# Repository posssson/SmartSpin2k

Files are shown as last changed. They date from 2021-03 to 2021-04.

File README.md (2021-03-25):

Watch the video (https://youtu.be/cPiIlZ2P5Ac)
Http://GitHub.com/doudar/SmartSpin2K
# SmartSpin2K

Hardware (3d Printed) and Software Project that uses an ESP32 and stepper motor to control spin bikes that have a resistance knob. 
The initial target was to use it with Zwift: stationary bike up hills and feel the burn. 

Optionally, the SmartSpin2K project has also progressed to the point of where it's useful without the hardware as a BLE device multiplexer, heart rate to watt converter (estimator), and proprietary BLE device to normal FTMS protocol converter using only the redily availiable ~$6 ESP32 devkit.   

## Background
I travel for a living and some hotels I stay at have spin bikes. I started carrying my own power meter pedals for the spin bikes so I could ride Zwift, but the experience just isn't the same without automatic resistance on the hills. Then one day I was looking down at that simple to turn knob and I had a thought - With the power meter pedals attached, almost everything is already in place on this $300 spin bike to turn it into the equivalent of a $3,000 computer controlled smart bike! And so here we are....

## NEW Instrucable!
Check it out at https://www.instructables.com/Spin-Bike-Controller/

## Summary of function

Communications Overview 

Your power meter (Or optionally the SmartSpin2K's built in HR->PWR calculation) connects to SmartSpin2k which then relays power and cadence to Zwift (or any other cycling app) via bluetooth as a controllable smart trainer. SmartSpin2k simulates gradient recieved from the app by automatically turning the knob a set amount for each percent grade change on your virtual road. SmartSpin2k also supports ERG mode which lets the unit directly control your resistance to match a specified watt target set by the connected app. In addition to adjusting the knob, SmartSpin2k also has shifter buttons to simulate virtual shifting. One of the nice features of having these shifters is that you can use them in ERG mode to get a jump on upcoming intervals. 

There are a multitude of configuration options availiable via a web interface on the SmartSpin2k. Automatic updates are also preformed on a regular basis if you choose to connect SmartSpin2k to your home network.  

### Recomended Hardware:

You'll need the quantity listed below of each item except the driver board. An optional PCB is in the hardware library which makes the wiring much simpler! 

| qty | Part | Amazon | Aliexpress |
|-----|:---:|---|---|
| 1 | ESP32 Dev Board | https://amzn.to/2ZNyjQX | https://www.aliexpress.com/item/1005001267643044.html |
| 1 | NEMA 17 Pancake Stepper | https://amzn.to/37mKKHh | https://www.aliexpress.com/item/4000120288783.html |
| 1 | TMC2225 | https://amzn.to/3kctdEQ | https://www.aliexpress.com/item/4000296898203.html |
| 1 | LM2596 Buck Converter | https://amzn.to/33ofggY | https://www.aliexpress.com/item/33014890815.html |
| 1 | 24V Power Supply | https://amzn.to/3r4e1i0 | https://www.aliexpress.com/item/32975192317.html |
| 2 | Tactile Switches | https://amzn.to/33ezmKx | https://www.aliexpress.com/item/32958087576.html |
| 2 | 608 Skate Bearings | https://amzn.to/3isBzrW | https://www.aliexpress.com/item/32700232097.html | 

So for $700-$1000 (or much less if you use HR2VP) you can build a fully functional smart bike! If you already have a Peloton bike collecting dust in the corner, this will work on that too! 

Surprisingly, my spin bike with the SmartSpin2K actually has better "road feel" than my expensive bike trainer, and since it's a belt drive bike, it's virtually silent. That's somthing you cannot achieve with a chain driven bike on any smart trainer. 

# NEW! - Small quantity of kits availiable!
If you would like a kit with a PCB, send a request to SmartSpin2K@gmail.com . Cost is $175 + shipping for all the printed parts + electronics, for an "almost ready to use unit". Note that if you go this route, this is still an open source hardware project and responsibility lies with **you** as to the proper construction and use. As such, you'll want to at least pull the cover off before use and take a look to ensure it's built to your standards (I think it's pretty good:) I'll be putting these togather on an as ordered basis, so expect 3-5 days prior to shipping.  Please see https://github.com/doudar/SmartSpin2k/wiki/Fitting-the-SmartSpin2k!

### We're working really hard on full documentaion
If you're adventerious and handy you can probably take a look at my pictures below or the assembly video and start tinkering. Please check out our new Instructable at https://www.instructables.com/Spin-Bike-Controller/ If there are any questions on the Instructable, please add info in the discussions and we will clarify there and on the new Instructable. This is a growing community and we now have a few members that would love to help you to get your SmartSpin2k working. There's also a wiki at https://github.com/doudar/SmartSpin2k/wiki 

In short, the process is:

### If you aren't a software developer:
1. Download https://github.com/doudar/SmartSpin2k/releases/download/0.1.1.11/firmware.bin
2. Download the SmartSpin2K flash tool https://github.com/SmartSpin2K/SmartSpin2kFlasher/releases/
3. Plug in your ESP32, open the SmartSpin2K flash tool and flash the firmware.bin.
4. Connect to the new wireless network SmartSpin2K (password is password) and enter your home network information, then the ESP32 will finish the installation automatically. 

### If you are a developer: 
1. Install Microsoft Visual Code. https://code.visualstudio.com/
2. Install PlatformIO into Visual Code. https://platformio.org/platformio-ide
3. Open this project in PlatformIO.  
4. Compile the project and upload to an ESP32

### Continue from either method above:
5. Print all the hardware. You'll need 1 Bottom Case, 1 Knob Cup, Both Spur Gears, 1 Stepper Crossbar, 1 Top Cover and a knob insert that fits your spin bike. PETG works well for printing all hardware.
6. If you're using the same switches for the shifters, you can optionally print the provided files. Previously I was using tape as a protective enclosure and it worked fine (if ugly).
7. Wire all of the connections outside the case. Use push on connectors if possible. 
8. Press both bearings into the recess.
9. Install the power supply, stepper driver and ESP32 into their brackets.
10. Install the power plug and shifter plug. 
11. Push the large gear down into the bearing. From the other side slide the knob cup onto it's shaft.  
12. Attach the stepper crossbar to the stepper motor.
13. Install the stepper motor. 
14. Put the cover on. 
15. Connect to the SmartSpin2k Wifi network for initial configuration. Default password is "password". If connecting via mobile, the configuration page should automatically pop up. 
16. Once configured on your local network, you can easily find the Smartspin2k by going to http://SmartSpin2K.local/

For some additional help, there are assembly pictures here that will be going into an instructable. https://github.com/doudar/SmartSpin2k/tree/master/Pictures/Assembly

ummm that was easy...right? :)

### Esp32 Connection Diagram
esp32 connections 

### TMC2225 Connection Diagram
esp32 connections 

*note, you can use an A4988 stepper driver also but you'll need to manually set the driver current with a screwdriver as well as possibly modify the output pin settings in /include/settings.h . If you do so, you'll aslo want to turn off automatic firmware updates. 

Cad Preview

The Finished assembly looks somthing like this prototype. 

On bench with shifters

Here it is mounted on a bike (ignore the piece of wood, it's no longer needed with a different hard attachment strap). 



Installed on a random Schwinn bike at the Gym:
Installed On Schwinn

...And here it is on a cheap magnetic HMC trainer off Amazon:
Installed on HMC

Here is the earliest prototype mounted on a spin bike. (Cardboard wrapped in ducktape enclosure :) ) 

Assembled SideView

Any help or feedback is greatly appreciated.

## Contributing
1. Install Microsoft Visual Code. https://code.visualstudio.com/
2. Install PlatformIO into Visual Code. https://platformio.org/platformio-ide
3. Install Pre-commit. https://pre-commit.com
4. Install pre-push git hooks: `pre-commit install --hook-type pre-push`
5. Open this project in PlatformIO.

## Licensing
The hardware designs in this project are licensed under the [CERN Open Hardware Licence Version 2 - Permissive license](Hardware/LICENSE).
The software in this project is licensed under the [GNU GENERAL PUBLIC LICENSE Version 2, June 1991 license](LICENSE).

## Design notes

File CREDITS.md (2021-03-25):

# Credits
Thanks to the authors of these libraries :
- [NimBLE-Arduino](https://github.com/h2zero/NimBLE-Arduino)
- [ArduinoJson](https://arduinojson.org)
- [TMCStepper](https://github.com/teemuatlut/TMCStepper)
- [Universal-Arduino-Telegram-Bot](https://github.com/witnessmenow/Universal-Arduino-Telegram-Bot)
- [FastAccelStepper](https://github.com/gin66/FastAccelStepper)

Thanks to Neil Kolban for his [BLE code examples](https://github.com/nkolban).

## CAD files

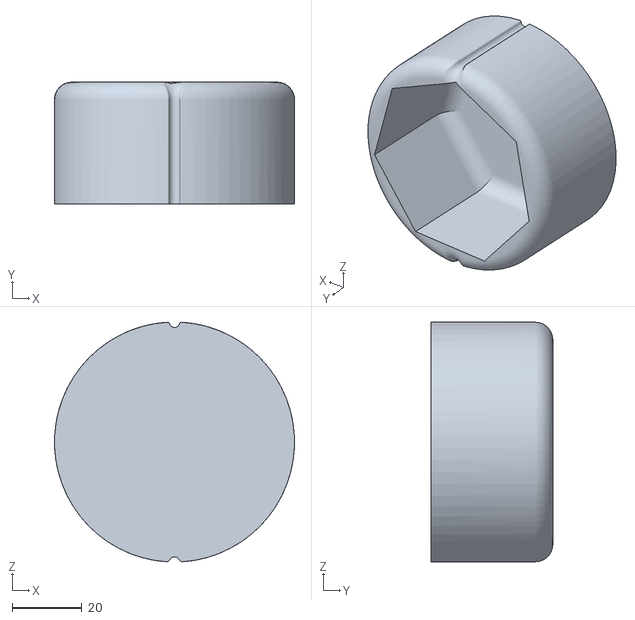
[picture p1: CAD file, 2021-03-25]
Hardware/Inserts/Peloton_7_flat.STL
69.0 x 35.0 x 68.9

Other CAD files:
Hardware/Inserts/Solidworks_Designs/Peloton_7_flat.SLDPRT

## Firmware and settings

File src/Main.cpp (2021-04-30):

/*
 * Copyright (C) 2020  Anthony Doud & Joel Baranick
 * All rights reserved
 *
 * SPDX-License-Identifier: GPL-2.0-only
 */

#include "Main.h"
#include <TMCStepper.h>
#include <Arduino.h>
#include <SPIFFS.h>
#include <HardwareSerial.h>

String debugToHTML = "<br>Firmware Version " + String(FIRMWARE_VERSION);
bool lastDir       = true;  // Stepper Last Direction

// Debounce Setup
uint64_t lastDebounceTime = 0;    // the last time the output pin was toggled
uint64_t debounceDelay    = 1000;  // the debounce time; increase if the output flickers

// Stepper Speed - Lower is faster
int maxStepperSpeed = 600;
int shifterPosition = 0;
int stepperPosition = 0;
HardwareSerial stepperSerial(2);
TMC2208Stepper driver(&SERIAL_PORT, R_SENSE);  // Hardware Serial

// Setup for BLEScan via shifters.
int shiftersHoldForScan = SHIFTERS_HOLD_FOR_SCAN;
uint64_t scanDelayTime  = 10000;
uint64_t scanDelayStart = 0;
bool scanDelayRunning   = false;

// Setup a task so the stepper will run on a different core than the main code
// to prevent stuttering
TaskHandle_t moveStepperTask;

///////////// Initialize the Config /////////////
userParameters userConfig;
physicalWorkingCapacity userPWC;

///////////// BEGIN SETUP /////////////
#ifndef UNIT_TEST
void setup() {
  // Serial port for debugging purposes
  Serial.begin(512000);
  stepperSerial.begin(57600, SERIAL_8N2, STEPPERSERIAL_RX, STEPPERSERIAL_TX);
  debugDirector("Compiled " + String(__DATE__) + String(__TIME__));

  // Initialize SPIFFS
  debugDirector("Mounting Filesystem");
  if (!SPIFFS.begin(true)) {
    debugDirector("An Error has occurred while mounting SPIFFS");
    return;
  }

  // Load Config
  userConfig.setDefaults();  // Preload defaults incase config.txt is missing any data
  userConfig.loadFromSPIFFS();
  userConfig.printFile();  // Print userConfig.contents to serial
  userConfig.saveToSPIFFS();

  // load PWC for HR to Pwr Calculation
  userPWC.loadFromSPIFFS();
  userPWC.printFile();
  userPWC.saveToSPIFFS();

  pinMode(RADIO_PIN, INPUT_PULLUP);
  pinMode(SHIFT_UP_PIN, INPUT_PULLUP);    // Push-Button with input Pullup
  pinMode(SHIFT_DOWN_PIN, INPUT_PULLUP);  // Push-Button with input Pullup
  pinMode(LED_PIN, OUTPUT);
  pinMode(ENABLE_PIN, OUTPUT);
  pinMode(DIR_PIN, OUTPUT);   // Stepper Direction Pin
  pinMode(STEP_PIN, OUTPUT);  // Stepper Step Pin
  digitalWrite(ENABLE_PIN,
               HIGH);  // Should be called a disable Pin - High Disables FETs
  digitalWrite(DIR_PIN, LOW);
  digitalWrite(STEP_PIN, LOW);
  digitalWrite(LED_PIN, LOW);

  setupTMCStepperDriver();

  debugDirector("Setting up cpu Tasks");
  disableCore0WDT();  // Disable the watchdog timer on core 0 (so long stepper
                      // moves don't cause problems)

  xTaskCreatePinnedToCore(moveStepper,           /* Task function. */
                          "moveStepperFunction", /* name of task. */
                          900,                   /* Stack size of task */
                          NULL,                  /* parameter of the task */
                          18,                    /* priority of the task  - 29 worked  at 1 I get stuttering */
                          &moveStepperTask,      /* Task handle to keep track of created task */
                          0);                    /* pin task to core 0 */

  digitalWrite(LED_PIN, HIGH);

  startWifi();

  // Check for firmware update. It's important that this stays before BLE &
  // HTTP setup because otherwise they use too much traffic and the device
  // fails to update which really sucks when it corrupts your settings.
  if (userConfig.getautoUpdate()) {
    FirmwareUpdate();
  }

  setupBLE();
  startHttpServer();
  resetIfShiftersHeld();
  debugDirector("Creating Shifter Interrupts");
  // Setup Interrups so shifters work anytime
  attachInterrupt(digitalPinToInterrupt(SHIFT_UP_PIN), shiftUp, CHANGE);
  attachInterrupt(digitalPinToInterrupt(SHIFT_DOWN_PIN), shiftDown, CHANGE);
  digitalWrite(LED_PIN, HIGH);
}

void loop() {
  vTaskDelay(1000 / portTICK_RATE_MS);
  scanIfShiftersHeld();

  if (debugToHTML.length() > 500) {  // Clear up memory
    debugToHTML = "<br>HTML Debug Truncated. Increase buffer if required.";
  }

#ifdef DEBUG_STACK
  Serial.printf("Stepper: %d \n", uxTaskGetStackHighWaterMark(moveStepperTask));
#endif
}
#endif

void moveStepper(void *pvParameters) {
  int acceleration   = maxStepperSpeed;
  int targetPosition = 0;

  while (1) {
    targetPosition = shifterPosition + (userConfig.getIncline() * userConfig.getInclineMultiplier());
    //debugDirector("Cadence =" +String(userConfig.getSimulatedCad()),true,false);
    if (stepperPosition == targetPosition) {
      vTaskDelay(300 / portTICK_PERIOD_MS);
      if (connectedClientCount() == 0) {
        digitalWrite(ENABLE_PIN,
                     HIGH);  // disable output FETs so stepper can cool
      }
      vTaskDelay(300 / portTICK_PERIOD_MS);
    } else {
      digitalWrite(ENABLE_PIN, LOW);
      vTaskDelay(1);

      if (stepperPosition < targetPosition) {
        if (lastDir == false) {
          vTaskDelay(100);  // Stepper was running in opposite
                            // direction. Give it time to stop.
        }
        digitalWrite(DIR_PIN, HIGH);
        digitalWrite(STEP_PIN, HIGH);
        delayMicroseconds(acceleration);
        digitalWrite(STEP_PIN, LOW);
        delayMicroseconds(acceleration);
        stepperPosition++;
        lastDir = true;
        
      } else {  // must be (stepperPosition > targetPosition)
        if (lastDir == true) {
          vTaskDelay(100);  // Stepper was running in opposite
                            // direction. Give it time to stop.
        }
        digitalWrite(DIR_PIN, LOW);
        digitalWrite(STEP_PIN, HIGH);
        delayMicroseconds(acceleration);
        digitalWrite(STEP_PIN, LOW);
        //delayMicroseconds(acceleration);
        stepperPosition--;
        lastDir = false;
      }
    }
  }
}

bool IRAM_ATTR deBounce() {
  if ((millis() - lastDebounceTime) > debounceDelay) {  // <----------------This should be assigned it's own task and just switch a global bool whatever the reading is at, it's
                                                        // been there for longer than the debounce delay, so take it as the actual current state: if the button state has changed:
    lastDebounceTime = millis();
    return true;
  }

  return false;
}

///////////// Interrupt Functions /////////////
void IRAM_ATTR shiftUp() {  // Handle the shift up interrupt IRAM_ATTR is to keep the interrput code in ram always
  if (deBounce()) {
    if (!digitalRead(SHIFT_UP_PIN)) {  // double checking to make sure the interrupt wasn't triggered by emf
      shifterPosition = (shifterPosition + userConfig.getShiftStep());
      debugDirector("Shift UP: " + String(shifterPosition));
    } else {
      lastDebounceTime = 0;
    }  // Probably Triggered by EMF, reset the debounce
  }
}

void IRAM_ATTR shiftDown() {  // Handle the shift down interrupt
  if (deBounce()) {
    if (!digitalRead(SHIFT_DOWN_PIN)) {  // double checking to make sure the interrupt wasn't triggered by emf
      shifterPosition = (shifterPosition - userConfig.getShiftStep());
      debugDirector("Shift DOWN: " + String(shifterPosition));
    } else {
      lastDebounceTime = 0;
    }  // Probably Triggered by EMF, reset the debounce
  }
}

void resetIfShiftersHeld() {
  if ((digitalRead(SHIFT_UP_PIN) == LOW) && (digitalRead(SHIFT_DOWN_PIN) == LOW)) {
    debugDirector("Resetting to defaults via shifter buttons.");
    for (int x = 0; x < 10; x++) {  // blink fast to acknoledge
      digitalWrite(LED_PIN, HIGH);
      vTaskDelay(200 / portTICK_PERIOD_MS);
      digitalWrite(LED_PIN, LOW);
    }
    for (int i = 0; i < 20; i++) {
      userConfig.setDefaults();
      vTaskDelay(200 / portTICK_PERIOD_MS);
      userConfig.saveToSPIFFS();
      vTaskDelay(200 / portTICK_PERIOD_MS);
    }
    ESP.restart();
  }
}

void scanIfShiftersHeld() {
  if ((digitalRead(SHIFT_UP_PIN) == LOW) && (digitalRead(SHIFT_DOWN_PIN) == LOW)) {  // are both shifters held?
    debugDirector("Shifters Held " + String(shiftersHoldForScan));
    if (shiftersHoldForScan < 1) {  // have they been held for enough loops?
      debugDirector("Shifters Held < 1 " + String(shiftersHoldForScan));
      if ((millis() - scanDelayStart) >= scanDelayTime) {  // Has this already been done within 10 seconds?
        scanDelayStart += scanDelayTime;
        spinBLEClient.resetDevices();
        spinBLEClient.serverScan(true);
        shiftersHoldForScan = SHIFTERS_HOLD_FOR_SCAN;
        digitalWrite(LED_PIN, LOW);
        debugDirector("Scan From Buttons");
      } else {
        debugDirector("Shifters Held but timer not up " + String((millis() - scanDelayStart) >= scanDelayTime));
        shiftersHoldForScan = SHIFTERS_HOLD_FOR_SCAN;
        return;
      }
    } else {
      shiftersHoldForScan--;
    }
  }
}

// String Text to print, Optional Make newline, Optional Send to Telegram
void debugDirector(String textToPrint, bool newline, bool telegram) {
  if (newline) {
    Serial.println(textToPrint);
    debugToHTML += String("<br>") + textToPrint;
  } else {
    Serial.print(textToPrint);
    debugToHTML += textToPrint;
  }
#ifdef USE_TELEGRAM
  if (false) {
    sendTelegram(textToPrint);
  }
#endif
}

void setupTMCStepperDriver() {
  driver.begin();
  driver.pdn_disable(true);
  driver.mstep_reg_select(true);

  uint16_t msread = driver.microsteps();
  debugDirector(" read:ms=" + msread);

  driver.rms_current(userConfig.getStepperPower());  // Set motor RMS current
  //driver.microsteps(4);                              // Set microsteps to 1/8th
  driver.irun(255);
  driver.ihold(200);      // hold current % 0-255
  driver.iholddelay(10);  // Controls the number of clock cycles for motor
                          // power down after standstill is detected
  driver.TPOWERDOWN(128);
  msread               = driver.microsteps();
  uint16_t currentread = driver.cs_actual();

  debugDirector(" read:current=" + currentread);
  debugDirector(" read:ms=" + msread);

  driver.toff(5);
  bool t_bool = userConfig.getStealthchop();
  driver.en_spreadCycle(!t_bool);
  driver.pwm_autoscale(t_bool);
  driver.pwm_autograd(t_bool);
}

void updateStepperPower() {
  debugDirector("Stepper power is now " + String(userConfig.getStepperPower()));
  driver.rms_current(userConfig.getStepperPower());
}

void updateStealthchop() {
  bool t_bool = userConfig.getStealthchop();
  driver.en_spreadCycle(!t_bool);
  driver.pwm_autoscale(t_bool);
  driver.pwm_autograd(t_bool);
  debugDirector("Stealthchop is now " + String(t_bool));
}

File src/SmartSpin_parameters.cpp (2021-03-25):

/*
 * Copyright (C) 2020  Anthony Doud & Joel Baranick
 * All rights reserved
 *
 * SPDX-License-Identifier: GPL-2.0-only
 */

#include "Main.h"
#include "SmartSpin_parameters.h"

#include <ArduinoJson.h>
#include <SPIFFS.h>

// Default Values
void userParameters::setDefaults() {  // Move these to set the values as #define
                                      // in main.h
  firmwareUpdateURL     = FW_UPDATEURL;
  incline               = 0.0;
  simulatedWatts        = 00;
  simulatedHr           = 00;
  simulatedCad          = 00;
  deviceName            = DEVICE_NAME;
  shiftStep             = 600;
  stepperPower          = STEPPER_POWER;
  stealthchop           = STEALTHCHOP;
  inclineMultiplier     = 3.0;
  doublePower           = false;
  simulateHr            = true;
  ERGMode               = false;
  autoUpdate            = AUTO_FIRMWARE_UPDATE;
  ssid                  = DEVICE_NAME;
  password              = DEFAULT_PASSWORD;
  foundDevices          = "";
  connectedPowerMeter   = "any";
  connectedHeartMonitor = "any";
}

//---------------------------------------------------------------------------------
//-- return all config as one a single JSON string
String userParameters::returnJSON() {
  // Allocate a temporary JsonDocument
  // Don't forget to change the capacity to match your requirements.
  // Use arduinojson.org/assistant to compute the capacity.
  StaticJsonDocument<USERCONFIG_JSON_SIZE> doc;
  // Set the values in the document

  doc["firmwareUpdateURL"]     = firmwareUpdateURL;
  doc["incline"]               = incline;
  doc["simulatedWatts"]        = simulatedWatts;
  doc["simulatedHr"]           = simulatedHr;
  doc["simulatedCad"]          = simulatedCad;
  doc["deviceName"]            = deviceName;
  doc["shiftStep"]             = shiftStep;
  doc["stepperPower"]          = stepperPower;
  doc["stealthchop"]           = stealthchop;
  doc["inclineMultiplier"]     = inclineMultiplier;
  doc["doublePower"]           = doublePower;
  doc["simulateHr"]            = simulateHr;
  doc["ERGMode"]               = ERGMode;
  doc["autoUpdate"]            = autoUpdate;
  doc["ssid"]                  = ssid;
  doc["password"]              = password;
  doc["foundDevices"]          = foundDevices;
  doc["connectedPowerMeter"]   = connectedPowerMeter;
  doc["connectedHeartMonitor"] = connectedHeartMonitor;
  String output;
  serializeJson(doc, output);
  return output;
}

//-- Saves all parameters to SPIFFS
void userParameters::saveToSPIFFS() {
  // Delete existing file, otherwise the configuration is appended to the file
  SPIFFS.remove(configFILENAME);

  // Open file for writing
  debugDirector("Writing File: " + String(configFILENAME));
  File file = SPIFFS.open(configFILENAME, FILE_WRITE);
  if (!file) {
    debugDirector(F("Failed to create file"));
    return;
  }

  // Allocate a temporary JsonDocument
  // Don't forget to change the capacity to match your requirements.
  // Use arduinojson.org/assistant to compute the capacity.
  StaticJsonDocument<USERCONFIG_JSON_SIZE> doc;

  // Set the values in the document

  doc["firmwareUpdateURL"] = firmwareUpdateURL;
  doc["incline"]           = incline;
  // doc["simulatedWatts"]       = simulatedWatts;
  // doc["simulatedHr"]          = simulatedHr;
  // doc["simulatedCad"]         = simulatedCad;
  doc["deviceName"]        = deviceName;
  doc["shiftStep"]         = shiftStep;
  doc["stepperPower"]      = stepperPower;
  doc["stealthchop"]       = stealthchop;
  doc["inclineMultiplier"] = inclineMultiplier;
  doc["doublePower"]       = doublePower;
  doc["simulateHr"]        = simulateHr;
  doc["ERGMode"]           = ERGMode;
  doc["autoUpdate"]        = autoUpdate;
  doc["ssid"]              = ssid;
  doc["password"]          = password;
  // doc["foundDevices"]         = foundDevices; //I don't see a need
  // currently in keeping this boot to boot
  doc["connectedPowerMeter"]   = connectedPowerMeter;
  doc["connectedHeartMonitor"] = connectedHeartMonitor;

  // Serialize JSON to file
  if (serializeJson(doc, file) == 0) {
    debugDirector(F("Failed to write to file"));
  }
  // Close the file
  file.close();
}
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

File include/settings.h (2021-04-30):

/*
 * Copyright (C) 2020  Anthony Doud & Joel Baranick
 * All rights reserved
 *
 * SPDX-License-Identifier: GPL-2.0-only
 */

#pragma once

// Update firmware on boot?
#define AUTO_FIRMWARE_UPDATE true

// Default Bluetooth WiFi and MDNS Name
#define DEVICE_NAME "SmartSpin2K"

// Default WiFi Password
#define DEFAULT_PASSWORD "password"

// default URL To get Updates From.
// If changed you'll also need to get a root certificate from the new server
// and put it in /include/cert.h
#define FW_UPDATEURL "https://github.com/posssson/BinSmartSpin.git/"

// File that contains Version info
#define FW_VERSIONFILE "version.txt"

// Path to the latest Firmware
#define FW_BINFILE "firmware.bin"

// Path to the latest filesystem
#define FW_SPIFFSFILE "spiffs.bin"

// name of local file to save configuration in SPIFFS
#define configFILENAME "/config.txt"

// name of local file to save Physical Working Capacity in Spiffs
#define userPWCFILENAME "/userPWC.txt"

// Default Stepper Power
#define STEPPER_POWER 1000

// Hardware pin for rocker Switch
#define RADIO_PIN 27

// Hardware pin for Shift Up
#define SHIFT_UP_PIN 19

// Hardware pin for Shift Down
#define SHIFT_DOWN_PIN 18

// Hardware pin for stepper Enable
#define ENABLE_PIN 13

// Hardware pin for stepper step
#define STEP_PIN 25

// Hardware pin for stepper dir
#define DIR_PIN 33

// TMC2208/TMC2224 SoftwareSerial receive pin
#define STEPPERSERIAL_RX 14

// TMC2208/TMC2224 SoftwareSerial transmit pin
#define STEPPERSERIAL_TX 12

// TMC2208/TMC2224 HardwareSerial port
#define SERIAL_PORT stepperSerial

// Match to your driver
// SilentStepStick series use 0.11
// UltiMachine Einsy and Archim2 boards use 0.2
// Panucatt BSD2660 uses 0.1
// Watterott TMC5160 uses 0.075
#define R_SENSE 0.11f

// Hardware pin for indicator LED *note* internal LED on esp32 Dev board is pin
// 2
#define LED_PIN 2

// Max tries that BLE client will perform on reconnect
#define MAX_RECONNECT_TRIES 10

// When quick reconnect fails ^^, we try to scan for the disconnected server.
// Scans slow BLE & WiFi traffic so we don't want to do this forever.
// Give up scanning for the lost connection after this many tries:
#define MAX_SCAN_RETRIES 1

// loop speed for the SmartSpin2k BLE communications
#define BLE_NOTIFY_DELAY 999

// loop speed for the SmartSpin2k BLE Client reconnect
#define BLE_CLIENT_DELAY 1000

// Number of devices that can be connected to the Client (myBLEDevices size)
#define NUM_BLE_DEVICES 4

// loop speed for the Webserver
#define WEBSERVER_DELAY 30

// Name of default Power Meter. any connects to anything, none connects to
// nothing.
#define CONNECTED_POWER_METER "ASSIOMA36290L"

// Name of default heart monitor. any connects to anything, none connects to
// nothing.
#define CONNECTED_HEART_MONITOR "any"

// number of main loops the shifters need to be held before a BLE scan is
// initiated.
#define SHIFTERS_HOLD_FOR_SCAN 2

// stealthchop enabled by default
#define STEALTHCHOP true

// how long to try STA mode before falling back to AP mode
#define WIFI_CONNECT_TIMEOUT 10

// Max size of userconfig
#define USERCONFIG_JSON_SIZE 768

// Uncomment to enable sending Telegram debug messages back to the chat
// specified in telegram_token.h
#define USE_TELEGRAM

// Uncomment to enable stack size debugging info
// #define DEBUG_STACK

// Uncomment to enable HR->PWR debugging info. Always displays HR->PWR
// Calculation. Never sets userConfig.setSimulatedPower(); #define
// DEBUG_HR_TO_PWR

#ifdef USE_TELEGRAM
// Max number of telegram messages to send per session
#define MAX_TELEGRAM_MESSAGES 5
// Filler definitions for if telegram_token.h is not included (because it has
// sensitive information). Do not change these as this file is tracked and
// therefore public. Enter your own Telegram info into telegram_token.h
#if __has_include("telegram_token.h")
#include "telegram_token.h"
#else
#define TELEGRAM_TOKEN   "1234567890:ABCDEFGHIJKLMNOPQRSTUVWXYZabcdefghi"
#define TELEGRAM_CHAT_ID "1234567890"
#endif
#endif

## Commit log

2021-03-22 Initial Test with new driver
2021-03-22 Added Defines for speed. Modified enable pin logic
2021-03-23 Increased stepper acceleration and speed
